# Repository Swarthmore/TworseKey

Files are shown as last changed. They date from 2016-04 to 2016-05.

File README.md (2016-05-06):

This is an update of the [original project by Martin Kaltenbrunner](http://modin.yuri.at/tworsekey).

Tworse Key is an Arduino-powered Telegraph that transmits its messages to Twitter.  Inspired by Martin Kaltenbrunner's original 2012 project, students, faculty, and staff at Swarthmore College have updated the code to work with the newer Twitter API and added the ability to work with Wifi or Ethernet connections.  

Students in Professor Rachel Buurma's Victorian Novel Research Seminar at Swarthmore College built a bunch of Twitter telegraphs.

![image of wifi Twitter telegraph](https://lh3.googleusercontent.com/L02vxvcqnI_aJqlpOlvz9yQV1sykd9xZOuwSR3vdNPqIrvYjRj3Nb9NSxXWy8DGmM5ELPkIyb-HGlXI2lQlwzxKvjPnNICS9roqN3yR-_pXc6AnJ9x_dknc8qKv7bbuUJW2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 "Image of Twitter telegraph")

image of Twitter telegraph Image of Twitter telegraph

# Hardware
Part| Notes
--- | --- 
Arduino Uno | Or Equivalent.  We purchased an [equivalent model from Sparkfun](https://www.sparkfun.com/products/12757).
Arduino Ethernet shield or Wifi shield | We purchased Sparkfun: [Ethernet](https://www.sparkfun.com/products/11229) or [Wifi](https://www.sparkfun.com/products/11287)
Morse Key|Model AM-K1 Telegraph Key sourced from [Morse Technologies](http://mtechnologies.com/) 
Piezo buzzer| We purchased a [12mm model from Sparkfun](https://www.sparkfun.com/products/7950) and [Amazon](http://www.amazon.com/Terminals-Electronic-Continuous-Sound-Buzzer/dp/B00B0Q4KKO/ref=sr_1_7)
RGB LED (common anode)| We purchased [this part from Sparkfun](https://www.sparkfun.com/products/10821)
330&Omega; resistor| for red portions of the RGB LED
Two 160&Omega; resistors| for green and blue portions of the RGB LED
50&Omega; resistor|For the buzzer
Breadboard | To plug in the electrical components. [A small one works fine](https://www.sparkfun.com/products/12046)
Hookup wire | To connect the parts 
Box or Wooden board | To mount the components

# Hardware setup 
Hook up the parts as in the diagram below
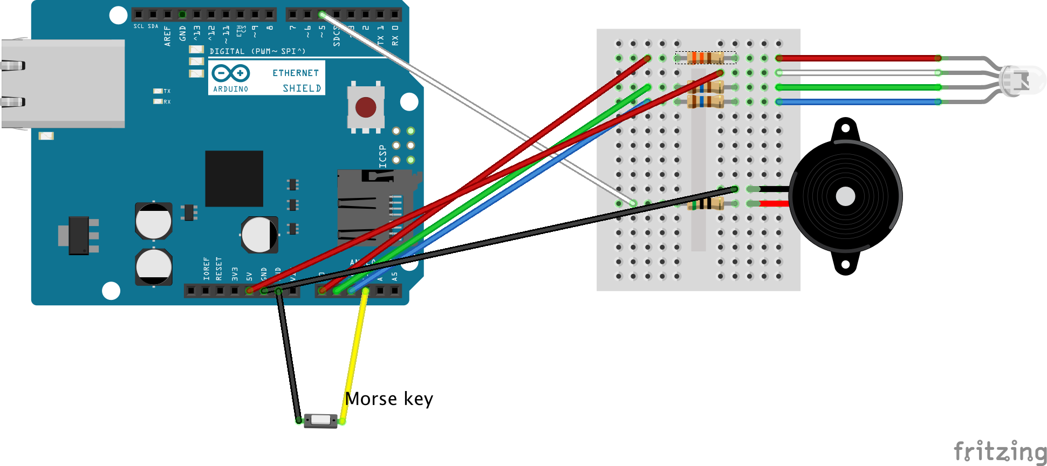
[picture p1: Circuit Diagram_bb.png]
circuit diagram Circuit diagram


# Software setup
* Open the Arduino program: https://www.arduino.cc/en/Main/Software
* If you are using Ethernet, download the Ethenet2 Arduino library from https://github.com/adafruit/Ethernet2/archive/master.zip
  * The regular Ethernet library only works with older Ethernet shields.  The Ethernet 2 library is required for newer shields.
  * Unzip the master.zip file, Find the "src" folder, and copy it into the Documents → Arduino → libraries folder.
* In the Arudino app, under  the "Tools → Board" menu, select "Arduino / Genuino Uno"
* Connect your Arduino to your computer with the USB cable
* Under the "Tools → Port" menu select something like "dev/cu.usbmodem"
* Download TworseKey program from GitHub: (https://github.com/Swarthmore/TworseKey) by clicking on the "Download Zip" option.
* Unzip the file, open the folder, and double click on the "TworseKey.ino" to open up the code.

## Twitter connection
The Arduino is not sophisticated enough to authenticate to Twitter and send a Tweet.  We are using IFTTT.com to send the tweets for us.  
* Go to IFTTT.com, create an account, and then make a new recipe.  
* The Recipe is: If Maker Event "tweet", then post a tweet to <your Twitter handle>
  * You will need to add the Maker and Twitter channels and do whatever authentication is required.

## Configuration
* Open the config_dist.h file (should be a tab in the Arduino program)
* Open a new tab (arrow on far right) and create a config.h file.  Copy and paste the content from config_hist.h to config.h
* Modify config.h with the MAC address from your Ethernet or Wifi board.  Include "0x" in front of each set of two characters
* Edit the code for Wifi or Ethernet
* Enter your Maker Key set up from IFTTT.com
* Modify hashtag(s) as you see fit
* Save config.h
* Click the check button on the top left of the window to verify everything is ok. 
* If so, click the right arrow button to upload your code to the Arduino

# Operation
After the Arduino is first powered up, it will look for a network connection. The LED will be yellow.  The wifi can take a while to connect.  Once a network connection is established, the LED will turn green and tone will sound.

Press the Morse key down for a short time for a dot and longer time for a dash.  The defaults are 150mS or shorter is a dot and 150mS to 600mS is a dash.  These can be modified in the main program. Pauses for more than a 1.5 seconds will automatically add a space.

Press the key down for more than 3 seconds to send the message to twitter.  The LED will turn blue while the message is sent.  A tone will indicate success or failure.  

Type 8 dots to reset your message.

You can use the Arduino serial monitor to see what you are typing.  

If you want to test out the system without sending lots of crazy tweets, you can update your IFTTT.com recipe to record your messages to a Google spreadsheet instead of sending to Twitter.  

# Original README
Tworse Key http://modin.yuri.at/tworsekey
(c) 2012 by Martin Kaltenbrunner

The Tworse Key is an open design exercise in interface archaeology,  that decodes the input from a classic Morse key to send twitter messages. This standalone device connects through a standard LAN cable, the Morse signals are decoded by the built-in Arduino Ethernet board, which delivers the final message though the Twitter API. 

This project is fully documented in order to illustrate the Open Design process for beginners, the source code and building instructions are therefore available under the according free licenses. 

This project is using NeoCat's Twitter library:
http://arduino-tweet.appspot.com/

All source code is available under the GPL 3.0 and the hardware schematics are available under a Creative Commons 3.0 BY-SA license. You can find all documentation and building instructions on the project page.

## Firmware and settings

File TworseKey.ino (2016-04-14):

/*
Copyright (c) 2012 Martin Kaltenbrunner
http://modin.yuri.at/tworsekey/

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
You should have received a copy of the GNU General Public License
along with this program.  If not, see <http://www.gnu.org/licenses/>.
*/


#include "config.h"
#include <SPI.h>

#if WIFI
  #include <WiFi.h>
  WiFiClient client;
  int status = WL_IDLE_STATUS;     // the Wifi radio's status
#else
  #include <Ethernet2.h>
  EthernetClient client;
#endif

byte mac[] = ARDUINO_ETHERNET_MAC;

// Define constants for LED colors
#define BLACK 0 // Off
#define RED 1
#define GREEN 2
#define BLUE 3
#define YELLOW 4
#define PURPLE 5
#define AQUA 6
#define WHITE 7

#define buzzPin  5
#define rledPin A0
#define gledPin A1
#define bledPin A2
#define morsePin A3

#define DIT 100 // mS
#define DAH 300 // mS


#define networkClientTimeout 3000


// This IP address is used if DHCP fails
byte ip[] = { 192, 168, 2, 2 };

// Message to post
char msg[] = "";

boolean keyDown = false;
boolean paused = false;
boolean addedSpace = false;
unsigned long time = 0;

String morseCode = "";
String message = "";
int maxMessageLength = 140;


char LATIN_CHARACTERS[] = {
        // Numbers
        '0', '1', '2', '3', '4',
        '5', '6', '7', '8', '9',
        // Letters 
        'a', 'b', 'c', 'd', 'e', 
        'f', 'g', 'h', 'i', 'j', 
        'k', 'l', 'm', 'n', 'o', 
        'p', 'q', 'r', 's', 't', 
        'u', 'v', 'w', 'x', 'y', 'z', 
        // Special
        '.', '?', '@', ' '
    };

String MORSE_CHARACTERS[] = {
        // Numbers
        "-----", ".----", "..---", "...--", "....-",
        ".....", "-....", "--...", "---..", "----.", 
        // Letters
        ".-",    "-...",  "-.-.",  "-..", ".", 
        "..-.",  "--.",   "....",  "..",  ".---",
        "-.-",   ".-..",  "--",    "-.",  "---",
        ".--.",  "--.-",  ".-.",   "...",  "-",     
        "..-",   "...-",  ".--",   "-..-", "-.--",  "--..",
        // Special
        ".-.-.-", "..--..", ".--.-.", " "
    };
    
    


    
// Program setup    
void setup() {
  
  // define the pins
  pinMode(rledPin, OUTPUT);
  pinMode(gledPin, OUTPUT);
  pinMode(bledPin, OUTPUT);  
  pinMode(buzzPin, OUTPUT);     // output for the buzzer
  pinMode(morsePin, INPUT);     // input from the morse switch 
  digitalWrite(morsePin, HIGH); // turns on pull-up resistor
  
  // Set LED color
  set_led_color(YELLOW);

  // Setup URL
  strcat(MAKER_PAGE, MAKER_KEY);
  
  // initialize serial and ethernet connections
  Serial.begin(9600);
  delay(1000);
  setupNetwork();

  client.setTimeout(networkClientTimeout);

  // Calculate the maximum message length (based on extra hashtags)
  maxMessageLength = 140 - strlen(TWITTER_HASHTAG);

  // Start timer
  time = millis();
}



#if WIFI

  // Setup wifi connection
  void setupNetwork() {
   // check for the presence of the shield:
    if (WiFi.status() == WL_NO_SHIELD) {
      Serial.println("WiFi shield not present");
      // don't continue:
      while (true);
    }
  
    String fv = WiFi.firmwareVersion();
    if (fv != "1.1.0") {
      Serial.println(F("Please upgrade the firmware"));
    }
  
    // attempt to connect to Wifi network:
    while (status != WL_CONNECTED) {
      Serial.print(F("Attempting to connect to WPA SSID: "));
      Serial.println(ssid);
      // Connect to WPA/WPA2 network:
      status = WiFi.begin(ssid, pass);
  
      // wait 5 seconds for connection:
      delay(5000);
    }

    connectionSuccessful();
  
    // you're connected now, so print out the data:
    Serial.print(F("You're connected to the wifi network"));
    // print your WiFi shield's IP address:
    IPAddress ip = WiFi.localIP();
    Serial.print("IP Address: ");
    Serial.println(ip);
    Serial.println(ip);
  
    // print your MAC address:
    byte mac[6];
    WiFi.macAddress(mac);
    Serial.print("MAC address: ");
    Serial.print(mac[5], HEX);
    Serial.print(":");
    Serial.print(mac[4], HEX);
    Serial.print(":");
    Serial.print(mac[3], HEX);
    Serial.print(":");
    Serial.print(mac[2], HEX);
    Serial.print(":");
    Serial.print(mac[1], HEX);
    Serial.print(":");
    Serial.println(mac[0], HEX);
  }

#else 

  // Setup Ethernet connection
  void setupNetwork() {
    
    paused = true;
    Serial.println(F("Connecting to Ethernet...")); 
    
    if (!Ethernet.begin(mac)) {
      // if DHCP fails, start with the default IP address:
      Ethernet.begin(mac, ip);
      Serial.print(F("using default IP address: "));
    } else {
      Serial.print(F("got IP address from DHCP: "));
    } 
    
    connectionSuccessful();
   
    Serial.println(Ethernet.localIP());
    paused = false;
  }

#endif


// Connection successful sound and make LED green
void connectionSuccessful() {
    // Play tone to indicate a successful connection
    tone(buzzPin, 440,100);
    delay(100);
    tone(buzzPin, 660,100);
    delay(100);
    tone(buzzPin, 880,300);
    delay(300);

    // change LED color to GREEN
    set_led_color(GREEN);
    
}

// Reset Morse Code message.  
// This is used when there is a timeout or after a message is sent out
void resetAll() {

    paused = true;
    set_led_color(RED);
    Serial.println(F("Reset message"));
    
    // play reset tone
    delay(200);   
    tone(buzzPin, 2000,50);
    delay(100);
    tone(buzzPin, 2000,50);
    delay(100);
    tone(buzzPin, 2000,50);
    delay(100);
    
    // reset strings and timer
    morseCode = "";
    message = "";
    time = millis();
    
    paused = false;
    set_led_color(BLACK);
}




// Given a Morse Code letter in the morseCode variable, look up the corresponding 
// letter and add it to the message variable.
void decodeMorse() {
  
  if (morseCode.length()==0) return;  // Don't bother decoding if the function is called without anything in the morseCode variable
  
  paused = true;
  set_led_color(PURPLE);
  
  // find character from table.
  // Loop through all the possibilities, until a match is found (or reach the end of the possibilities)
  bool decoded = false;
  for (int i=0;i<40;i++) {
     if (morseCode==MORSE_CHARACTERS[i]) {
        message+=LATIN_CHARACTERS[i];
        decoded = true;
        break;
     }
  } 

  // User feedback based on decoding success or failure
  if (!decoded) {
    // Couldn't decode the Morse code character.  
    // Add "*" to the message, play the decode error buzz, and show the red light.
    message+="*";
    set_led_color(RED);  
    tone(buzzPin,50);
    delay(50);
    tone(buzzPin,262, 100);
    delay(100);
  } else {
    // Decoding successful - play a happy tone
     tone(buzzPin, 2000,50);            
  }

  // Clear morseCode variable to get ready for the next letter and print out the message so far.
  morseCode = "";
  Serial.println("\n"+message);

  // If we reach the max message length, send out the Tweet.
  if (message.length()>=maxMessageLength) sendTweet();
  
  paused = false;
  set_led_color(BLACK);
}



// Send message to Maker webhook.  
// This will trigger IFTTT to send a Tweet.
byte httpPOST(char const* domainBuffer,int port,char const* page, String msg) {

  String jsonString = "{\"value1\":\"" + msg + "\"}";
  char jsonMessage[164];
  jsonString.toCharArray(jsonMessage,164);
 
  boolean result = false;

  Serial.print(F("Message: "));
  Serial.println(jsonMessage);

  client.stop();
  
  if(client.connect(domainBuffer, port)) {

    Serial.println("Connected");

    // send the header
    client.print(F("POST "));
    client.print(page);
    client.print(F(" HTTP/1.1\r\n"));

    client.print(F("Host: "));
    client.print(domainBuffer);
    client.print("\r\n");
    
    client.print(F("Connection: close\r\nContent-Type: application/json\r\nContent-Length: "));
    client.print(strlen(jsonMessage));
    client.print(F("\r\n\r\n"));
    
    // send the body (variables)
    client.println(jsonMessage);

    Serial.println("Done sending message");
    
    if(client.available()>0 && client.find("200 OK")) {
      Serial.println(F("Message received"));
      result = true;
    } else {
      Serial.println(F("Message not received"));
    }

  } else {
    Serial.println(F("POST failed"));
  }

  client.stop();
  client.flush();
  return result;
}




// Set LED color
void set_led_color(int color) {
  
  // Turn all LED's off
  digitalWrite(rledPin, HIGH);
  digitalWrite(gledPin, HIGH);  
  digitalWrite(bledPin, HIGH);  
  
   switch(color)  {
     case RED:
       digitalWrite(rledPin, LOW);
       break;     
     case GREEN:
       digitalWrite(gledPin, LOW);
       break;       
     case BLUE:
       digitalWrite(bledPin, LOW);
       break;       
     case YELLOW:
       digitalWrite(rledPin, LOW);
       digitalWrite(gledPin, LOW);
       break;  
     case PURPLE:
       digitalWrite(rledPin, LOW);
       digitalWrite(bledPin, LOW);
       break;      
     case AQUA:
       digitalWrite(gledPin, LOW);
       digitalWrite(bledPin, LOW);
       break;   
     case WHITE:
       digitalWrite(rledPin, LOW);
       digitalWrite(gledPin, LOW);       
       digitalWrite(bledPin, LOW);
       break;         
   }
   
}


// Main program loop
void loop() {  
  
  if (paused) return; // Skip if in the middle of something else
 
  unsigned long duration = millis() - time;  // Figure out how long the key has been pressed/released
  
  if (digitalRead(morsePin) == HIGH) {     
    
    // the morse key is currently UP
    if (keyDown) {       
         // the key was DOWN before (i.e. the key was just released)            
        // If the key was pressed for a very short time, just ignore
        if (duration<20) return;

        // Otherwise, turn off the LED and buzzer, and set KeyDown to false to indicate the key is no longer being pressed
        set_led_color(BLACK);        // turn LED  OFF
        noTone(buzzPin);             // turn BUZZ OFF
        keyDown = false;
        addedSpace = false;          // Space has not been added

        // Determine if key was pressed for a DIT or DAH duration
        if (duration < (DIT+50) ) {           // DIT detected
          morseCode+=".";
          Serial.print(".");
          
          // If there are a series of DITs -- reset the message
          if (morseCode=="........") resetAll();
          
        } else if (duration<(2*DAH)) {    // DAH detected
          morseCode+="-";
          Serial.print("-");
        }
               
        time = millis();  // Reset the time.  This indicates how long the key is up for
      
    } else {   
      
      // the key was UP before (i.e. the key was up and still is up)
      if ( (duration>60000) && (message!="") ) {             // Reset the message after 60 seconds inactivity     
        resetAll();
       } else if ( (duration>DAH+100) && (duration<=1500) ) {  
        // If the key was up for between a DAH and 1.5 seconds, that is the 
        // end of a character (starting a new character)
        decodeMorse();   // decode last letter  
      } else if (duration>1500 && message!="" && !addedSpace) {     // start a new word after 1.5 seconds
          tone(buzzPin, 200,50);                                    // short feedback beep
          message += " ";
          addedSpace = true;
      }
    } // End of key UP
    
  } else {               
    
    // the morse key is currently DOWN   
    if (!keyDown) {      // the key was UP before (i.e. the key was just pressed)

      if (duration<20) {return;}     // If the key was released for a very short time, just ignore
        
      // Otherwise, turn on the LED and buzzer, and set KeyDown to true to indicate the key is being pressed
      set_led_color(GREEN);
      tone(buzzPin, 440);            // turn BUZZ ON
      keyDown = true;
      
      time = millis();    // Reset the time.  This indicates how long the key is down for
      
    } else {             // the key was already DOWN (i.e. the key was already being pressed before this loop)
    
      if ( ( duration > (DIT+50))  && (duration < 2*DAH) ) {
        set_led_color(AQUA);              // Change LED color for DAH
      } else if ( (duration > (2*DAH)) && (duration<1000) ) {
        set_led_color(WHITE);             // Turn off LED for greater than DAH
      } else if (duration>1000) {         // send tweet after pressing the key for one second
        
        // Turn off LED and buzzer, set keyDown to false (to reset timer)
        set_led_color(BLACK);
        noTone(buzzPin);            
        keyDown = false;
 
        sendTweet();         // Send the Tweet!       
      }
      
    } 
  }  // End of key up/down if statement
}




// Send out the Twitter message
void sendTweet() {

  char tweet[140];

  // Don't bother if there isn't a mesage
  if (message.length()==0) return;
  
  // Switch LED to blue and pause other operations
  set_led_color(BLUE);
  paused = true;

  // Add the hashtag and convert the message String to a character array with max length 140 characters
  Serial.print(F("sending tweet ... "));
  message += TWITTER_HASHTAG;
  message.toCharArray(tweet,140);

  // POST the message to the MAKER URL
  if (httpPOST(MAKER_URL, MAKER_PORT, MAKER_PAGE, message)) {
      // Success! PLay happy tone
      tone(buzzPin, 440,100);
      delay(100);
      tone(buzzPin, 660,100);
      delay(100);
      tone(buzzPin, 880,300);
      delay(100); 
      
  } else {
      
      Serial.println(F("Sending Tweet failed"));
      // play error buzz and show red LED.  Then switch to green
      set_led_color(RED);
      tone(buzzPin, 100,1000); 
  }

  // Reset variables and get ready for next message
  set_led_color(GREEN);
  message = "";
  time = millis();
  paused = false;
}

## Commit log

2015-03-20 Modified pins to accommodate mp3 and added LED colors
2015-03-23 Fixed send tweet duration problem
    [TworseKey.ino]
2016-04-11 Use Ethernet2 for new boards
2016-04-12 Added circuit diagrams
    [Circuit Diagram.fzz]
2016-05-05 Update circuit diagram
    And .md to README
    [Circuit Diagram.fzz]
2016-05-05 Updated circuit image and removed old circuit diagram file.
    [TworseKey.fz]

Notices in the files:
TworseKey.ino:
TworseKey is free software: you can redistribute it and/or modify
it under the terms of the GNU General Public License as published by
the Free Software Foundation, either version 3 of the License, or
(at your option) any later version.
